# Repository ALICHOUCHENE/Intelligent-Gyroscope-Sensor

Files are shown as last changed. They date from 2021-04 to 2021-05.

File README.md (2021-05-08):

# Intelligent-Gyroscope-Sensor

Intelligent gyroscope sensor for Electronic stability control

Recognizing how a vehicle is steered and then alerting drivers in real time is of utmost importance to the vehicle and driver’s safety, since fatal accidents are often caused by dangerous vehicle maneuvers, such as rapid turns, fast lane-changes, etc.
In this paper, we make use of an intelligent sensor to take one step forward by developing a real-time accurate recognition system for dangerous vehicle steering maneuvers without the driver’s involvement. 
The basic idea is to use the sensor data to capture differences in the vehicle’s angular speed due to vehicle steering maneuvers, including turns, lane-changes and U-turns. 

 **Here the features of the Sensor :**

- STM32F103C8T6 ARM 32-bit Cortex™-M3 is the CPU of the board. Higher frequency, higher speed and cost-effictive.

- Gyroscope module, MPU6050, with I2C communication protocol. 

- CAN transeiver SN65HVD230

- SWD programming Interface.

- SPI for serial communication.

- USART for AT-commands mode in order to test the sensor before embedded it in the CAN bus.

- Voltage regulator with reverse voltage protection circuit.

**The schematic of the board :**

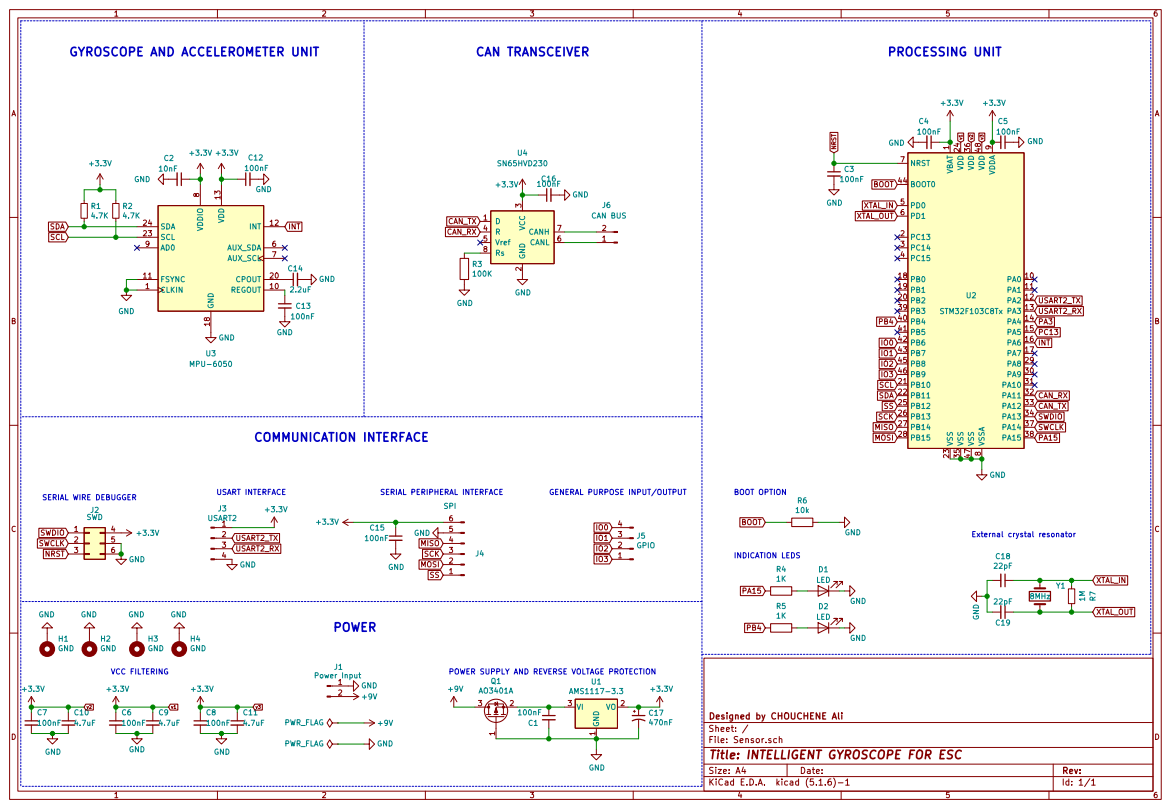
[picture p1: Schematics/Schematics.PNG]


**The PCB layout of the board :**

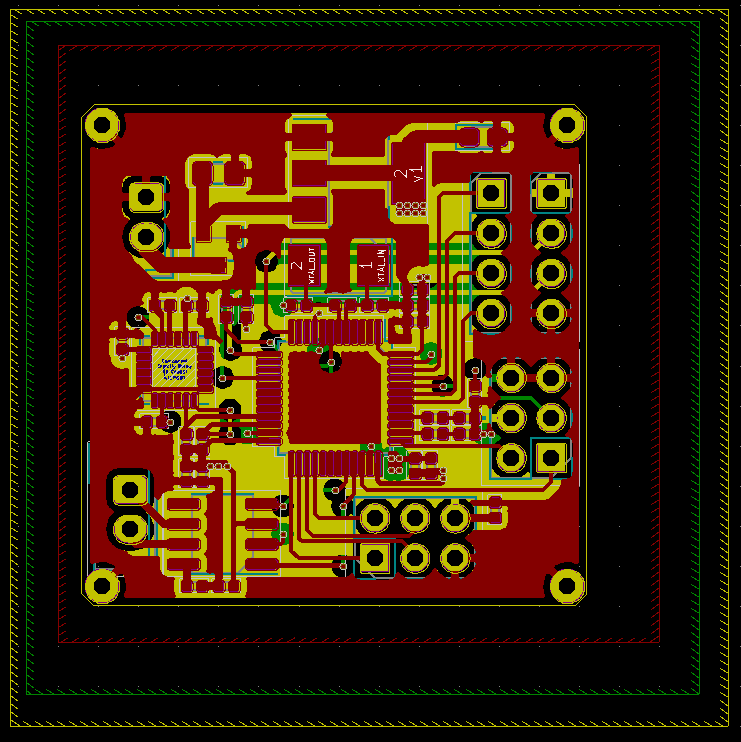
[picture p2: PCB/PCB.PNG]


**Board View :**

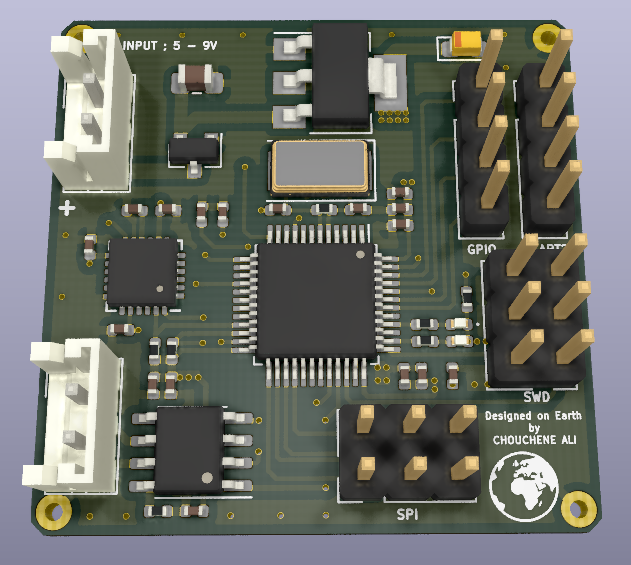
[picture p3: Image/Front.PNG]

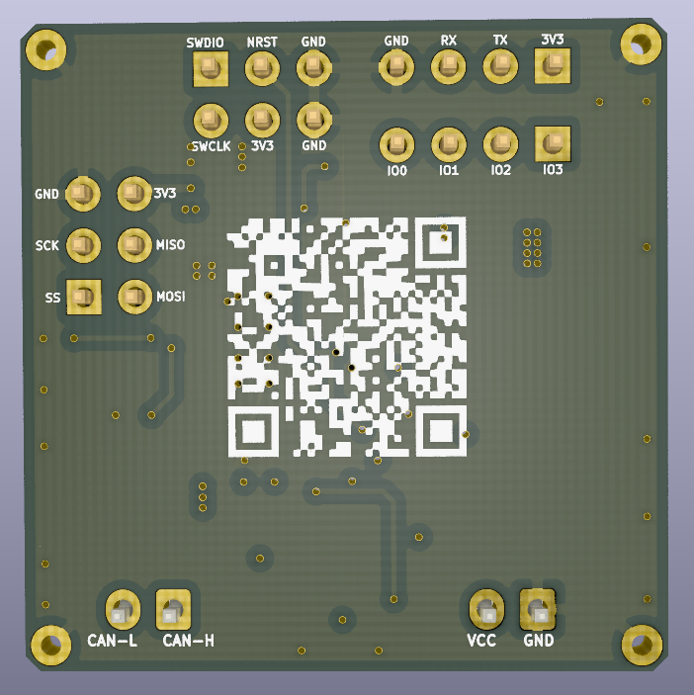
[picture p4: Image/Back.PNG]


# Manufacturing : 

After finishing the Routing and verifying the pcb. We will make the board at JLC PCB and we chose also the PCB Assembly service.
Here is the BOM and posistion file needed to order from JLC PCB :

**BOM :**

| Designator | Value | Footprint | LCSC Part |
|---|---|---|---|
| C1 | 100nF | Capacitor_SMD:C_0805_2012Metric_Pad1.15x1.40mm_HandSolder | C49678 |
| C2 | 10nF | Capacitor_SMD:C_0402_1005Metric | C1525 |
| C3 | 100nF | Capacitor_SMD:C_0402_1005Metric | C1525 |
| C4 | 100nF | Capacitor_SMD:C_0402_1005Metric | C1525 |
| C5 | 100nF | Capacitor_SMD:C_0402_1005Metric | C1525 |
| C6 | 100nF | Capacitor_SMD:C_0402_1005Metric | C1525 |
| C7 | 100nF | Capacitor_SMD:C_0402_1005Metric | C1525 |
| C8 | 100nF | Capacitor_SMD:C_0402_1005Metric | C1525 |
| C12 | 100nF | Capacitor_SMD:C_0402_1005Metric | C1525 |
| C13 | 100nF | Capacitor_SMD:C_0402_1005Metric | C1525 |
| C15 | 100nF | Capacitor_SMD:C_0402_1005Metric | C1525 |
| C16 | 100nF | Capacitor_SMD:C_0402_1005Metric | C1525 |
| C9 | 4.7uF | Capacitor_SMD:C_0402_1005Metric | C23733 |
| C10 | 4.7uF | Capacitor_SMD:C_0402_1005Metric | C23733 |
| C11 | 4.7uF | Capacitor_SMD:C_0402_1005Metric | C23733 |
| C14 | 2.2uF | Capacitor_SMD:C_0402_1005Metric | C12530 |
| C17 | 470nF | Capacitor_Tantalum_SMD:CP_EIA-2012-12_Kemet-R | |
| C18 | 22pF | Capacitor_SMD:C_0402_1005Metric | C70464 |
| C19 | 22pF | Capacitor_SMD:C_0402_1005Metric | C70464 |
| D1 | LED | LED_SMD:LED_0402_1005Metric | C71911 |
| D2 | LED | LED_SMD:LED_0402_1005Metric | C71911 |
| Q1 | AO3401A | Package_TO_SOT_SMD:SOT-23 | C15127 |
| R1 | 4.7K | Resistor_SMD:R_0402_1005Metric | C25900 |
| R2 | 4.7K | Resistor_SMD:R_0402_1005Metric | C25900 |
| R3 | 100K | Resistor_SMD:R_0402_1005Metric | C25741 |
| R4 | 1K | Resistor_SMD:R_0402_1005Metric | C11702 |
| R5 | 1K | Resistor_SMD:R_0402_1005Metric | C11702 |
| R6 | 10k | Resistor_SMD:R_0402_1005Metric | C25744 |
| R7 | 1M | Resistor_SMD:R_0402_1005Metric | C26083 |
| U1 | AMS1117-3.3 | Package_TO_SOT_SMD:SOT-223-3_TabPin2 | C6186 |
| U2 | STM32F103C8Tx | Package_QFP:LQFP-48_7x7mm_P0.5mm | C8734 |
| U3 | MPU-6050 | Sensor_Motion:InvenSense_QFN-24_4x4mm_P0.5mm | C24112 |
| U4 | SN65HVD230 | Package_SO:SOIC-8_3.9x4.9mm_P1.27mm | C12084 |
| Y1 | 8MHz | Crystal:Crystal_SMD_0603-2Pin_6.0x3.5mm | C111120 |

**Position file :**

| Designator | Value | Footprint | Mid X | Mid Y | Rotation | Layer |
|---|---|---|---|---|---|---|
| C1 | 100nF | C_0805_2012Metric_Pad1.15x1.40mm_HandSolder | 106.680000 | -76.708000  | 0.000000 | top |
| C2 | 10nF | C_0402_1005Metric | 105.156000 | -85.090000  | 0.000000 | top |
| C3 | 100nF | C_0402_1005Metric | 107.188000 | -85.344000  | 90.000000  | top |
| C4 | 100nF | C_0402_1005Metric | 119.126000 | -84.074000  | 180.000000 | top |
| C5 | 100nF | C_0402_1005Metric | 108.458000 | -85.344000  | 270.000000 | top |
| C6 | 100nF | C_0402_1005Metric | 120.142000 | -95.250000  | 90.000000  | top |
| C7 | 100nF | C_0402_1005Metric | 105.664000 | -95.758000  | 270.000000 | top |
| C8 | 100nF | C_0402_1005Metric | 119.126000 | -85.090000  | 180.000000 | top |
| C9 | 4.7uF | C_0402_1005Metric | 119.126000 | -95.250000  | 90.000000  | top |
| C10 | 4.7uF | C_0402_1005Metric | 104.648000 | -95.758000  | 270.000000 | top |
| C11 | 4.7uF | C_0402_1005Metric | 119.126000 | -86.106000  | 180.000000 | top |
| C12 | 100nF | C_0402_1005Metric | 100.584000 | -87.376000  | 90.000000  | top |
| C13 | 100nF | C_0402_1005Metric | 103.124000 | -85.090000  | 180.000000 | top |
| C14 | 2.2uF | C_0402_1005Metric | 102.616000 | -92.456000  | 180.000000 | top |
| C15 | 100nF | C_0402_1005Metric | 121.920000 | -95.250000  | 90.000000  | top |
| C16 | 100nF | C_0402_1005Metric | 107.188000 | -102.870000 | 180.000000 | top |
| C17 | 470nF | CP_EIA-2012-12_Kemet-R | 123.444000 | -74.422000  | 0.000000 | top |
| C18 | 22pF | C_0402_1005Metric | 116.586000 | -85.090000  | 0.000000 | top |
| C19 | 22pF | C_0402_1005Metric | 111.760000 | -85.090000  | 180.000000 | top |
| D1 | LED | LED_0402_1005Metric | 122.428000 | -93.218000  | 180.000000 | top |
| D2 | LED | LED_0402_1005Metric | 122.428000 | -92.202000  | 180.000000 | top |
| Q1 | AO3401A | SOT-23 | 106.680000 | -81.534000  | 270.000000 | top |
| R1 | 4.7K | R_0402_1005Metric | 105.664000 | -93.726000  | 90.000000  | top |
| R2 | 4.7K | R_0402_1005Metric | 104.648000 | -93.726000  | 90.000000  | top |
| R3 | 100K | R_0402_1005Metric | 105.156000 | -102.870000 | 0.000000 | top |
| R4 | 1K | R_0402_1005Metric | 120.396000 | -93.218000  | 180.000000 | top |
| R5 | 1K | R_0402_1005Metric | 120.396000 | -92.202000  | 180.000000 | top |
| R6 | 10k | R_0402_1005Metric | 122.936000 | -90.678000  | 90.000000  | top |
| R7 | 1M | R_0402_1005Metric | 114.554000 | -85.090000  | 180.000000 | top |
| U1 | AMS1117-3.3 | SOT-223-3_TabPin2 | 115.570000 | -76.708000  | 0.000000 | top |
| U2 | STM32F103C8Tx | LQFP-48_7x7mm_P0.5mm | 114.046000 | -90.932000  | 270.000000 | top |
| U3 | MPU-6050 | InvenSense_QFN-24_4x4mm_P0.5mm | 103.886000 | -89.154000  | 180.000000 | top |
| U4 | SN65HVD230 | SOIC-8_3.9x4.9mm_P1.27mm | 106.934000 | -99.568000  | 180.000000 | top |
| Y1 | 8MHz | Crystal_SMD_0603-2Pin_6.0x3.5mm | 114.300000 | -82.550000  | 180.000000 | top |

# Downloads

* [Board schematics](https://github.com/ALICHOUCHENE/Intelligent-Gyroscope-Sensor/blob/main/Schematics/Schematics.pdf)

* [BOM](https://github.com/ALICHOUCHENE/Intelligent-Gyroscope-Sensor/blob/main/Assembly/BOM.xlsx)

* [Position file](https://github.com/ALICHOUCHENE/Intelligent-Gyroscope-Sensor/blob/main/Assembly/Sensor-all-pos.xlsx)

* [Gerber File](https://github.com/ALICHOUCHENE/Intelligent-Gyroscope-Sensor/blob/main/GERBER/GERBER.rar)

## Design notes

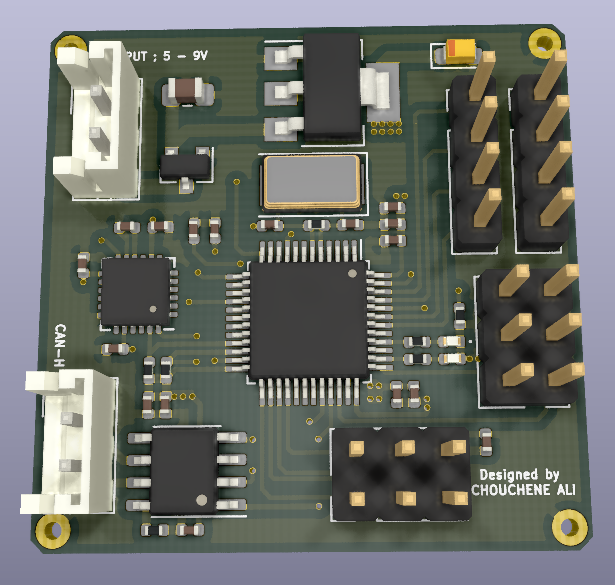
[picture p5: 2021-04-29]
PCB/3D.PNG

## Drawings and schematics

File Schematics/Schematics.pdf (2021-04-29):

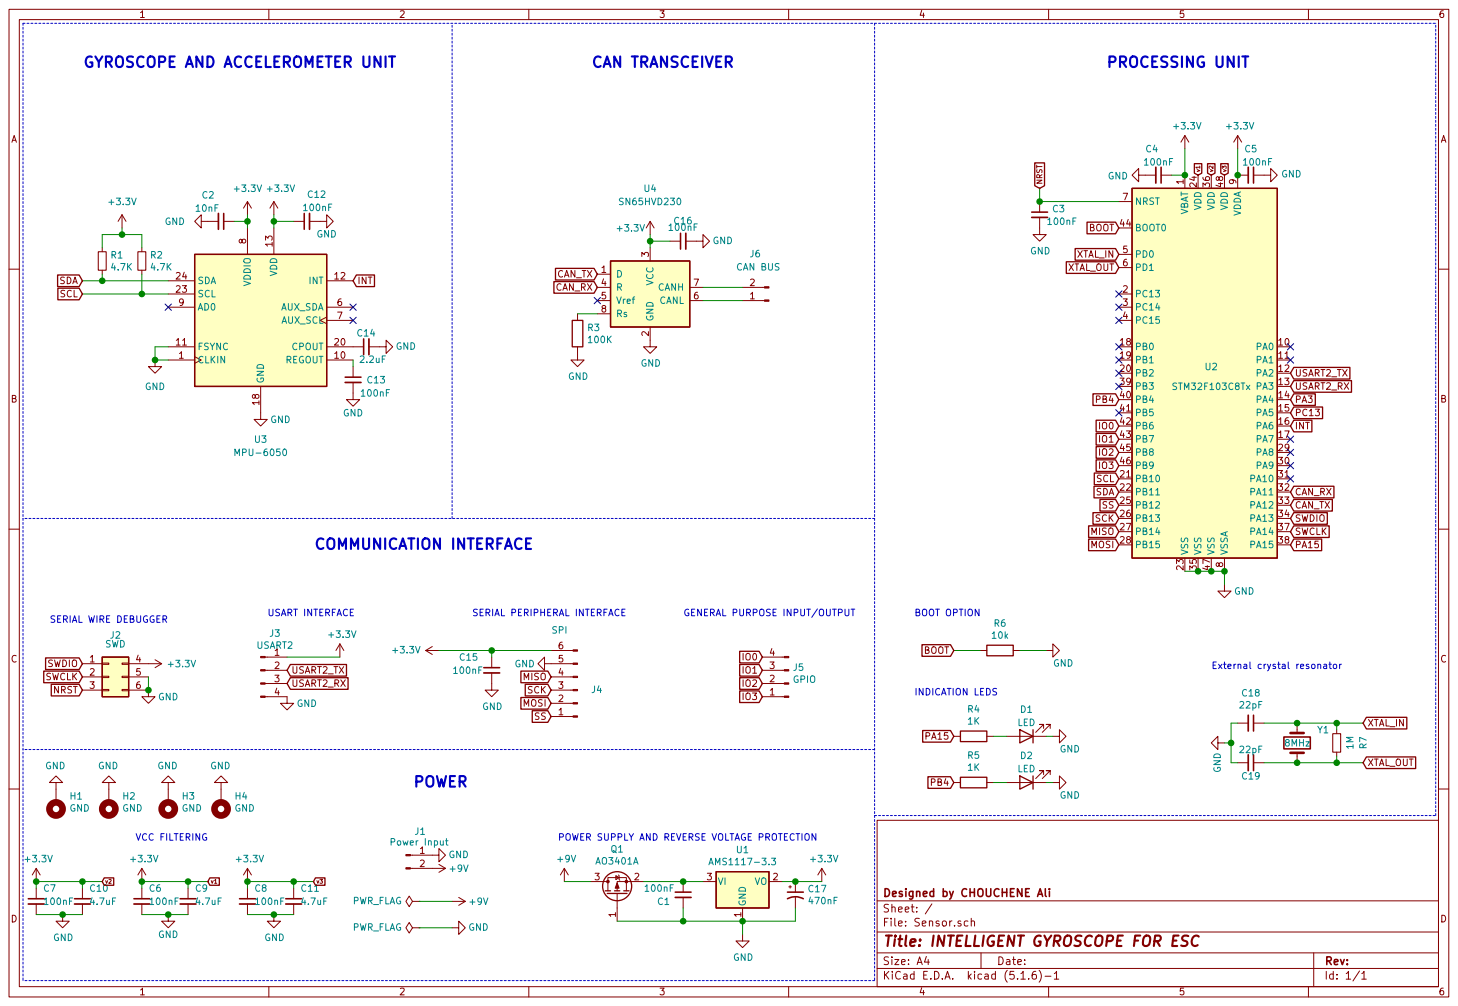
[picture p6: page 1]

GENERAL PURPOSE INPUT/OUTPUT GYROSCOPE AND ACCELEROMETER UNIT

1 VDD 24 VDD 36 VDD 48 VDDA

9 VSS 23 VSS 35 VSS 47 VSSA

INDICATION LEDS
File: Sensor.sch Sheet: / Designed by CHOUCHENE Ali D1

POWER SUPPLY AND REVERSE VOLTAGE PROTECTION

Id: 1/1 Title: INTELLIGENT GYROSCOPE FOR ESC

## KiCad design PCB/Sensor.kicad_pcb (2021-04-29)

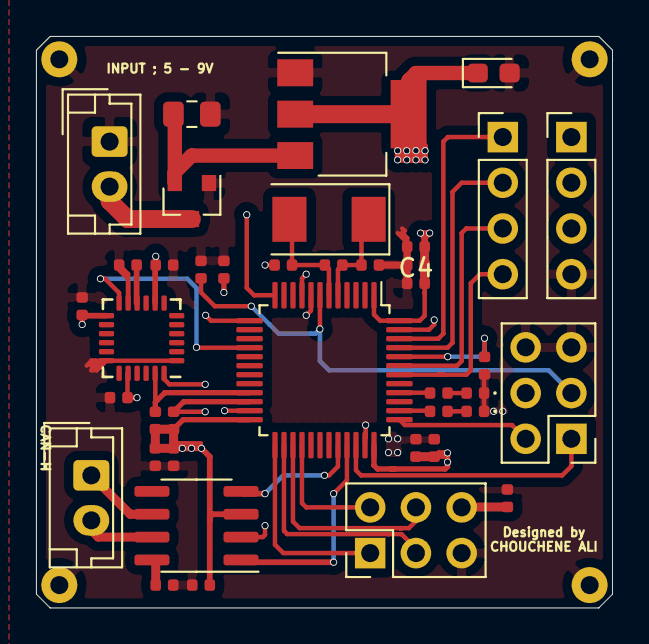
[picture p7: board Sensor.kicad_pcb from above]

Board: 4 copper layers, 32.0 x 31.8 mm, 44 parts (0 on the bottom side), 34 nets.

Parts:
C1: 100nF; C_0805_2012Metric_Pad1.15x1.40mm_HandSolder
C2: 10nF; C_0402_1005Metric
C3, C4, C5, C6, C7, C8, C12, C13, C15, C16: 100nF; C_0402_1005Metric
C9, C10, C11: 4.7uF; C_0402_1005Metric
C14: 2.2uF; C_0402_1005Metric
C17: 470nF; CP_EIA-2012-12_Kemet-R
C18, C19: 22pF; C_0402_1005Metric
D1, D2: LED; LED_0402_1005Metric
H1, H2, H3, H4: GND; MountingHole_2.2mm_M2_DIN965_Pad
J1: Power Input; JST_EH_B2B-EH-A_1x02_P2.50mm_Vertical
J2: SWD; PinHeader_2x03_P2.54mm_Vertical
J3: USART2; PinHeader_1x04_P2.54mm_Vertical
J4: SPI; PinHeader_2x03_P2.54mm_Vertical
J5: GPIO; PinHeader_1x04_P2.54mm_Vertical
J6: CAN BUS; JST_EH_B2B-EH-A_1x02_P2.50mm_Vertical
Q1: AO3401A; SOT-23
R1, R2: 4.7K; R_0402_1005Metric
R3: 100K; R_0402_1005Metric
R4, R5: 1K; R_0402_1005Metric
R6: 10k; R_0402_1005Metric
R7: 1M; R_0402_1005Metric
U1: AMS1117-3.3; SOT-223-3_TabPin2
U2: STM32F103C8Tx; LQFP-48_7x7mm_P0.5mm
U3: MPU-6050; InvenSense_QFN-24_4x4mm_P0.5mm
U4: SN65HVD230; SOIC-8_3.9x4.9mm_P1.27mm
Y1: 8MHz; Crystal_SMD_0603-2Pin_6.0x3.5mm

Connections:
+9V: J1.2, Q1.3
BOOT: R6.2, U2.44
CAN_RX: U2.32, U4.4
CAN_TX: U2.33, U4.1
GND: C1.2, C2.2, C3.2, C4.2, C5.1, C6.2, C7.2, C8.2, C9.2, C10.2, C11.2, C12.2, C13.2, C14.2, C15.2, C16.2, C17.2, C18.2, C19.2, D1.1, D2.1, H1.1, H2.1, H3.1, H4.1, J1.1, J2.5, J2.6, J3.4, J4.5, Q1.1, R3.2, R6.1, U1.1, U2.8, U2.23, U2.35, U2.47, U3.1, U3.11, U3.18, U4.2
INT: U2.16, U3.12
IO0: J5.4, U2.42
IO1: J5.3, U2.43
IO2: J5.2, U2.45
IO3: J5.1, U2.46
MISO: J4.4, U2.27
MOSI: J4.2, U2.28
NRST: C3.1, J2.3, U2.7
unnamed: C1.1, Q1.2, U1.3
unnamed: C13.1, U3.10
unnamed: C14.1, U3.20
unnamed: D1.2, R4.1
unnamed: D2.2, R5.1
unnamed: J6.1, U4.6
unnamed: J6.2, U4.7
unnamed: R3.1, U4.8
PA15: R4.2, U2.38
PB4: R5.2, U2.40
SCK: J4.3, U2.26
SCL: R2.2, U2.21, U3.23
SDA: R1.2, U2.22, U3.24
SS: J4.1, U2.25
SWCLK: J2.2, U2.37
SWDIO: J2.1, U2.34
USART2_RX: J3.3, U2.13
USART2_TX: J3.2, U2.12
XTAL_IN: C18.1, R7.1, U2.5, Y1.1
XTAL_OUT: C19.1, R7.2, U2.6, Y1.2
v1: C2.1, C4.1, C5.2, C6.1, C7.1, C8.1, C9.1, C10.1, C11.1, C12.1, C15.1, C16.1, C17.1, J2.4, J3.1, J4.6, R1.1, R2.1, U1.2, U2.1, U2.9, U2.24, U2.36, U2.48, U3.8, U3.13, U4.3
